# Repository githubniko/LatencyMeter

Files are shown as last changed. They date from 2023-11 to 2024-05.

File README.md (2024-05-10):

# Latency Meter FPV-systems & Camera

Устройство для измерения раздержки различных камер и FPV-систем. Оно построено на плате Ардуино Нано и 4х разрядном 7ми-сегментном индиаторе LED 5461AS-1.

* Версия 1.1 (для 2х-цветного светодиода): [https://github.com/githubniko/LatencyMeter/tree/v1.1](https://github.com/githubniko/LatencyMeter/tree/v1.1)
* Версия 2.0: отличие от 1.1 равномерым миганием без ожидания: [https://github.com/githubniko/LatencyMeter/tree/v2.0](https://github.com/githubniko/LatencyMeter/tree/v2.0)

**Кнопка:** Длинное нажатие на кнопку запускает процесс измерения сначала. Короткое - переключает показания индикатора между real-time, min, max, sma.

Видео по сборке: [https://www.youtube.com/watch?v=69uGeqPZ3CI](https://www.youtube.com/watch?v=69uGeqPZ3CI)

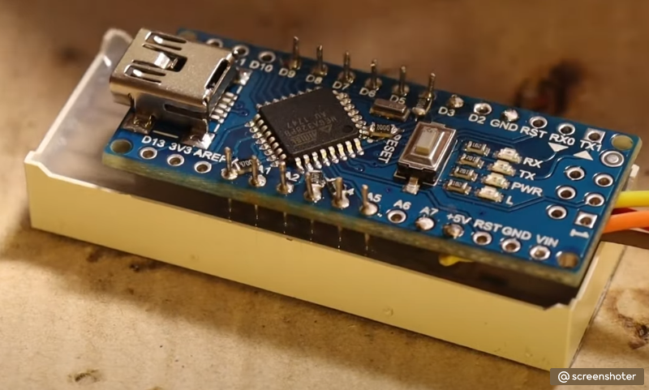
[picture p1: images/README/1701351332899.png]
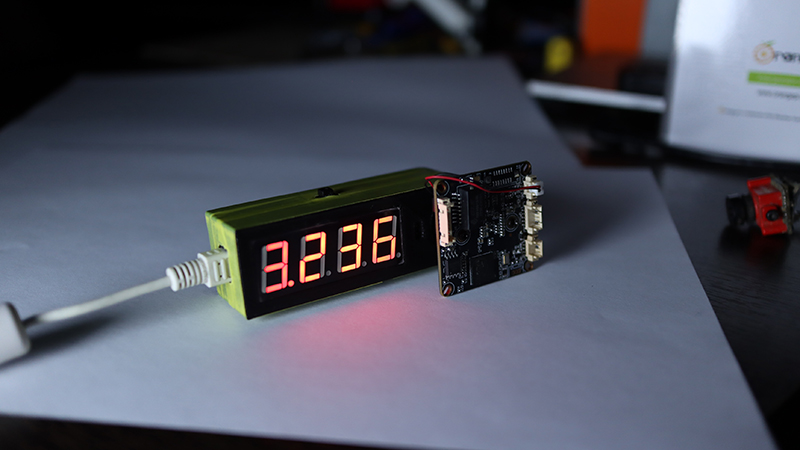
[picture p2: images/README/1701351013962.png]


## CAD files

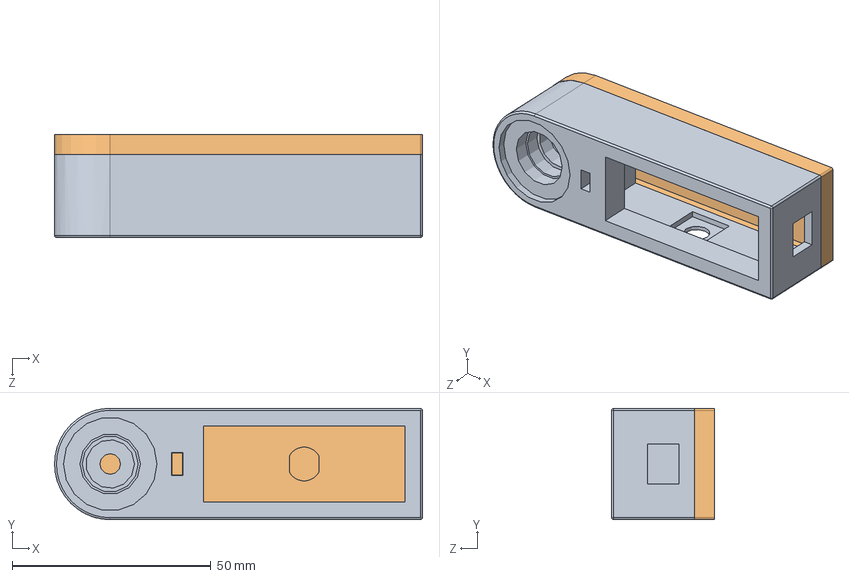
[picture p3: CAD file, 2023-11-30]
3d_model/Latency_IPCam.SLDASM
92.5 x 28.0 x 25.9 mm
Latency_IPCam
Крышка^Latency_IPCam

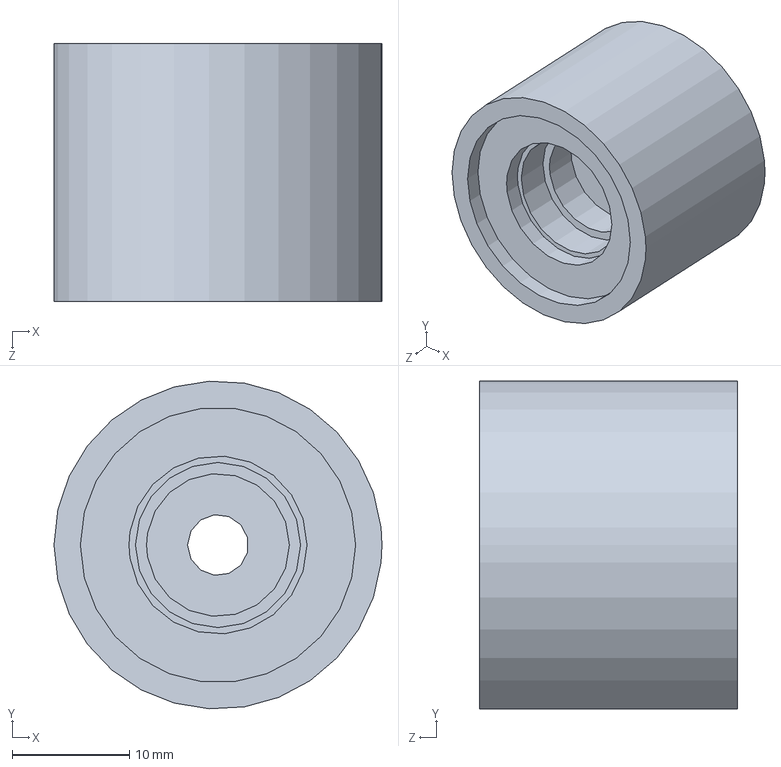
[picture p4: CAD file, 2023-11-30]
3d_model/Lens_housing.SLDPRT
28.0 x 28.0 x 22.0 mm

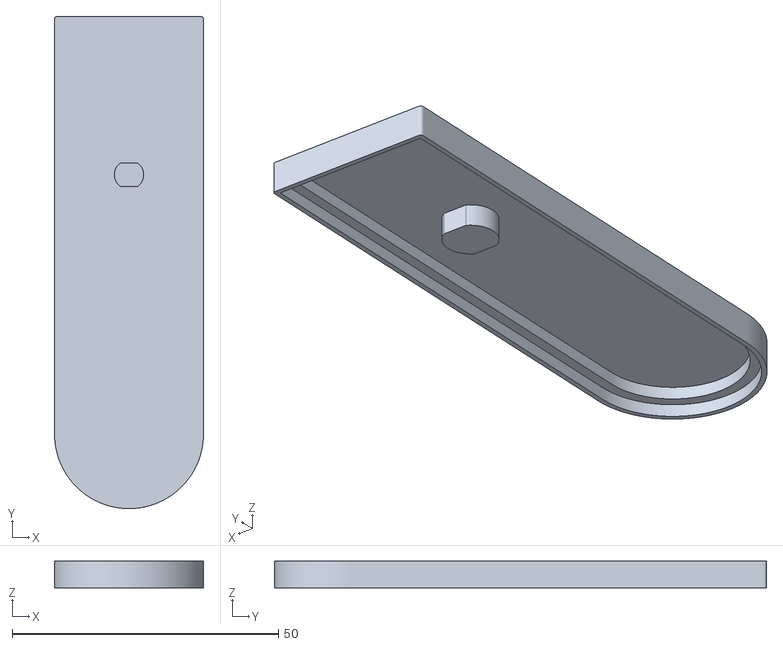
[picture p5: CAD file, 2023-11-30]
3d_model/STL/Latency_IPCam2.STL
28.0 x 92.5 x 5.00

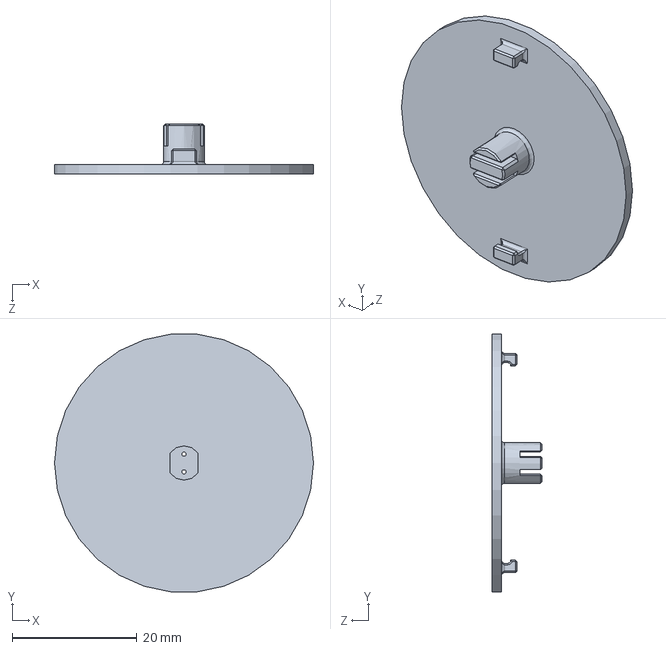
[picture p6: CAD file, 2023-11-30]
3d_model/Housing_for_VT83N1.SLDPRT
41.5 x 41.3 x 8.00 mm

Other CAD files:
3d_model/Latency_IPCam.SLDPRT
3d_model/STL/Housing_for_VT83N1.STL
3d_model/STL/Latency_IPCam.STL
3d_model/STL/Lens_housing.STL

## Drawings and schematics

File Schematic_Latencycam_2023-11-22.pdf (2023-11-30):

A | A

1

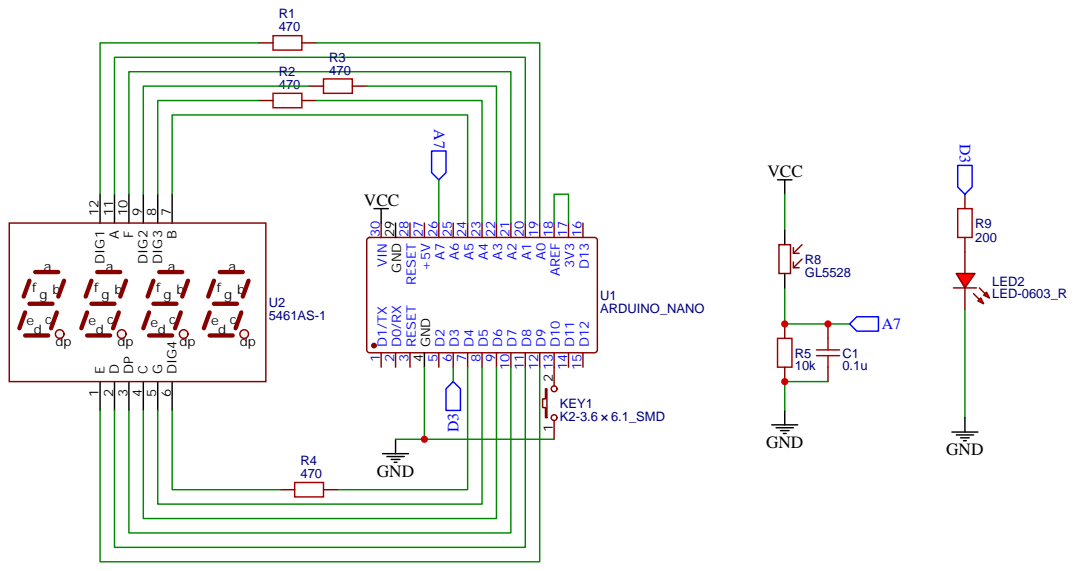
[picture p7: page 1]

D12 15 D13 16 3V3 17 AREF 18 A0 19 A1 20 A2 21 A3 22 A4 23 A5 24 A6 25 A7 26 +5V 27 RESET 28 GND 29 VIN 30

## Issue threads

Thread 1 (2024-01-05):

Неустойчивость длительности свечения светодиода

KimIV, 2024-01-05:
Я собрал Вашу схему на макетке для протестировать и залил последнюю версию скетча от 02.01.2024.

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

Схема сразу заработала в паре со скетчем, но напряг один момент. Я полагал так, что если светодиод направить на фоторезистор без посредников, то должна быть нулевая задержка. Но на индикаторе я увидел скачущие цифры от 0 до 3. Это было бОльшую часть времени наблюдения в течение нескольких десятков секунд. Но иногда (очень редко) проскакивали цифры 4, 5, 6 и 7. Я решил посмотреть осциллографом сигналы на светодиоде и фоторезисторе. Вот точки контроля по Вашей схеме.

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

И наблюдал интересную картину. Время свечения светодиода плавно увеличивалось. Потом резко уменьшалось и снова плавно увеличивалось. Но иногда резко увеличивалось и также резко уменьшалось. Вот ссылка на видео https://youtu.be/JZO6ssp1RjM

Тогда я решил откатиться к Вашей первоначальной версии latencymeter_old.hex Ситуация с нулевой задержкой на этой прошивке намного лучше. Цифры на индикаторе видны только 0 и 1. И время свечения светодиода уже не имеет плавных нарастаний, а есть только скачки. Вот скрины минимальной и максимальной длительностей свечения светодиода (жёлтый луч).

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

А также ссылка на видео https://youtu.be/XXs31W97c6k

PS. Я пока только обрисовал проблему. Изучаю Ваши исходники и пытаюсь понять, где собака порылась...

KimIV, 2024-01-05:
Ну и по ходу дела ещё один нюанс, на который я обратил внимание. У меня почему-то нет вот этой задержки между момент зажигания светодиода и моментом начала реакции фоторезистора. Вот скрин из Вашего видео по сборке. А мои скрины в предыдущем сообщении.

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

githubniko, 2024-01-05:
Эта задержка на последнем скриншоте не нужна. Почему она у меня была на видео не стал выяснять. Что касается плавного нарастания на осциллограммах, то оно у Вас ~0.8мс, у меня было на старой прошивке ~0.03мс. Новую прошивку не смотрел осциллографом. После праздников проверю обязательно.
Попробуйте закомментировать ресурсную функцию расчета медианы в latencymeter.h:90. Так же можно попробовать исключить конденсатор С1 на фоторезисторе. Еще важно, чтобы на фоторезистор не поступал лишний свет.

KimIV, 2024-01-06:
> Эта задержка на последнем скриншоте не нужна.

Это-то как раз понятно. Даже если бы она была, её необходимо было бы компенсировать программно. Просто я шёл по Вашим следам и удивлялся, почему мои "деревья растут вверх ногами" ))) Были даже сомнения сначала, может я где напортачил и что-то сделал не так. Какое-то время потратил на перепроверки. Ну и потом решил Ваше внимание обратить на это...

> Что касается плавного нарастания на осциллограммах, то оно у Вас ~0.8мс, у меня было на старой прошивке ~0.03мс.

Вы имеете в виду бинарник latencymeter_old.hex? Или была прошивка ещё первее? Просто два последних скрина в моём первом сообщении - это именно эта прошивка и там фронт импульса на фоторезисторе нарастает в диапазоне от 0,3 до 0,75мс. Я думаю, это скорострельность самого фоторезистора. Не смотря на то, что фронт параболический, можно всё-таки приближённо грубо взять за скорость нарастания фронта 0,2мс/В. И это даже компенсировать никак не надо, поскольку разрешение самого прибора 1мс. Меня больше волнует, почему идёт накопление задержки до 2 и даже изредка до 3мс.

> Попробуйте закомментировать ресурсную функцию расчета медианы в latencymeter.h:90.

Ооо... Вы как разработчик интуитивно чувствуете, где может быть засада! Отключение расчёта медианы стабилизировало длительность свечения светодиода. И она составила примерно 0,5мс.

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

> Так же можно попробовать исключить конденсатор С1 на фоторезисторе.

Это я пробовал. На последней прошивке его влияние уловить трудно, практически невозможно. Я не смог! А вот на бинарнике latencymeter_old.hex чётко видно, что конденсатор увеличивает время между вспышками светодиода. Ниже скрины с конденсатором и без.

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

> Еще важно, чтобы на фоторезистор не поступал лишний свет.

Да, я тоже это заметил. Лишний свет увеличивает "нулевую" задержку, т.к. реакция фоторезистора - это левая часть перевёрнутой параболы,

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

то "лишний" свет поднимает вверх по этой параболе рабочий участок и таким образом увеличивает время реакции фоторезистора. Я эту проблему решил, соединив фоторезистор со светодиодом бумажным тубусом.

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

> Почему-то у Вас напряжение на фотодиоде очень большое. Должно быть стартовое +0.5В. Установлено ли Uref = 3.3 ?

Да, установлено. Вывод REF наны соединён с выводом 3V3 и на данный момент там напряжение 3,236 В. Возможно, мне следует уменьшить сопротивление резистора R5. Это который 10к. Мой фоторезистор в темноте имеет сопротивление порядка 100к, а при ярком освещении - около 1к. Это обычный фоторезистор из комплекта Arduino Ultimate Uno R3 Starter Kit.

KimIV, 2024-01-06:
> Попробуйте закомментировать ресурсную функцию расчета медианы в latencymeter.h:90.

Я посидел над кодом, поразмышлял и мне стала понятная природа плавного нарастания времени свечения светодиода. Это происходит из-за увеличения списка данных, которые используются при расчёте медианы. Время работы функции median() прямопропорционально количеству данных, которое постепенно увеличивается. И что важно, это никак не влияет на "нулевую" задержку. То есть при плавном увеличении времени свечения светодиода мы всё равно можем наблюдать резкие скачки этого времени туда-сюда. А когда смотрим в монитор порта (туда пишет Serial.println(value); (latencymeter.h:119)), то видим цифры 0, 1, 2. Кстати, после того, как я соединил тубусом фоторезистор и светодиод перестала проскакивать цифра 3. И этот факт возвращает к мысли, что быстродействие фоторезистора может быть той самой собакой, которая порылась )))

KimIV, 2024-01-08:
После замены функции millis() на [micros()](https://github.com/githubniko/LatencyMeter/pull/3/commits/135b7523a1be15ed3dfb1190a304873c977ac3e8) я посмотрел осциллографом импульсы в тех же точках, которые указывал в первом сообщении. И вот, что увидел. Длительность свечения светодиода плавно растёт с момента старта измерений с 0,8 мс до 12 мс и далее стабилизируется. Изменение происходит только в первые 30 секунд. После этого длительность импульса постоянна и если точно составляет 11,88 мс.

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

[Ссылка на видео](https://youtu.be/riIVxjTF750), демонстрирующее процесс.

Меня лично вот это стартовое нарастание длительности свечения светодиода уже мало беспокоит. Главное, что удалось устранить непонятные скачки длительности свечения и нулевой задержки.

Что ещё имею сообщить? Для проверки я выводил в serial разницу между micros() и _timer, то есть до деления на 1000 для получения миллисекунд.

`                valueTime = (micros() - _timer) / 1000; // Считаем задержку`
`                Serial.print(micros() - _timer, DEC);`
`                Serial.print(' ');`
`                AddValue(valueTime);`

Так вот диапазон этих значений для нулевой задержки от 340 до 368 на довольно большой выборке (несколько тысяч). А типовое значение равно 344.

Closed 2024-01-09.

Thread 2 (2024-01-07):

Latency Meter. Неустойчивость LOW.

KimIV, 2024-01-07:
Я обнаружил ещё одну проблему. Но прежде, чем изложить её суть, предлагаю договориться о терминах. Предлагаю называть нулевой задержкой ситуацию, при которой светодиод направлен на фоторезистор либо в полной темноте, либо через тубус, который исключает попадание на фоторезистор постороннего света. Например, у меня это реализовано вот так.

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

Теперь суть проблемы. Я заметил, что при нулевой задержке скачет значение LOW. Я считаю, что LOW в данном случае всегда должно быть равно нулю. Вот ссылка на видео, демонстрирующее скачки LOW. То 0 (ноль), то 1 (единица).

https://youtu.be/nGoV20tnr8o

PS. Версия скетча последняя с закомментированным расчётом медианы
latencymeter.h:90`//                medianTime = round(median());`

githubniko, 2024-01-07:
Спасибо. Это баг. см latencymeter.h:84
Будет возникать когда minTime = 0.

githubniko, 2024-01-07:
Заднюю часть светодиода желательно закрасить черной краской.

Closed 2024-01-09.

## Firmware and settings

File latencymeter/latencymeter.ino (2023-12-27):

#define F_CPU 16000000UL // частота работы микроконтроллера

#define PIN_BUTTON 10

#include "Led_5461AS.h"
#include "Button.h"
#include "LatencyMeter.h"

Led_5461AS *led;
LatencyMeter *latencyMeter;
Button button1(PIN_BUTTON);

uint8_t flagTypeDataOut = 3; // 0 - задержка рела-тайм, 1 - минимальная, 2 - максимальная, 3 - медиана, 4 - кол-во измерений

class EventHandler
{
public:
  void OnUpdateData()
  {
    char buf[33];
    char str[10];

    switch (flagTypeDataOut)
    {
    case 1:
      dtostrf(latencyMeter->minTime, 3, 0, buf);
      strcpy(str, "L");
      break;
    case 2:
      dtostrf(latencyMeter->maxTime, 3, 0, buf);
      strcpy(str, "H");
      break;
    case 3:
      dtostrf(latencyMeter->medianTime, 3, 0, buf);
      strcpy(str, "^");
      break;
    case 4:
      itoa(latencyMeter->count, buf, 10);
      strcpy(str, "n");
      break;
    case 0:
    default:
      dtostrf(latencyMeter->valueTime, 4, 0, buf);
      strcpy(str, "");
      break;
    }
    strcat(str, buf);
    led->Set(str); // вывод на экран
  }
  void OnBtnClick()
  {
    flagTypeDataOut++;
    if (flagTypeDataOut > 4)
      flagTypeDataOut = 0;
    
    OnUpdateData();
  }
  void OnBtnReset()
  {
    latencyMeter->Start();
    // asm volatile("jmp 0x00"); // Перезагрузка
  }
};
EventHandler eventHandler;

void setup()
{
  Serial.begin(115200);

  led = new Led_5461AS();
  latencyMeter = new LatencyMeter();
  latencyMeter->onUpdate += METHOD_HANDLER(eventHandler, EventHandler::OnUpdateData);

  button1.onClick += METHOD_HANDLER(eventHandler, EventHandler::OnBtnClick);
  button1.onClickLong += METHOD_HANDLER(eventHandler, EventHandler::OnBtnReset);

  //latencyMeter->Start();
}

void loop()
{
  button1.Execute();
  latencyMeter->Execute();
}

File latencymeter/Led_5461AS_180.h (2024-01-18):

#pragma once

#define A PORTD5    // D5
#define B PORTB1    // D9
#define C PORTC2    // A2
#define D PORTC4    // A4
#define E PORTC5    // A5
#define F PORTD6    // D6
#define G PORTC1    // A1
#define DP PORTC3   // A3
#define DIG1 PORTD4 // D4
#define DIG2 PORTD7 // D7
#define DIG3 PORTB0 // D8
#define DIG4 PORTC0 // A0

#include <math.h>

class Led_5461AS
{
    static inline uint8_t count;
    static inline uint8_t offset; // Смещение. Нужно для точки или запятой
    static inline char *value;    // Хранит текущее число индикации

public:
    static inline uint8_t Length; // Размер строки

public:
    Led_5461AS()
    {
        value = "0";
        count = 1;
        offset = 0;
        Length = strlen(value);

        // Устанавливаю порты на выход
        DDRB = DDRB | B00011;
        DDRC = DDRC | B00111111;
        DDRD = DDRD | B11110000;

        // Таймер обновления индикации
        cli(); // отключить глобальные прерывания
        TCCR1A = 0;
        TCCR1B = 0;
        TCCR1B |= (1 << CS11);   // делитель 8
        TCCR1B |= (1 << WGM12);  // сброс по совпадению
        OCR1A = 2500;            // 10ms, 100Гц*4 = 480Гц, 16 000 000 / 8 * 400Гц * 2 = 2500
        TIMSK1 |= (1 << OCIE1A); // прерывание по переполнению

        sei(); // включить глобальные прерывания
    }

    /// @brief Устанавливает значение индикатора
    void Set(float number)
    {
        if (number > 9999)
            number = 9999;

        uint8_t pos = FindDecimalPoint(number);
        char buf[33];
        dtostrf(number, 4, 4 - pos, buf);
        Set(buf);
    }

    /// @brief Устанавливает значение индикатора
    void Set(int number)
    {
        if (number > 9999)
            number = 9999;

        char buf[33];
        itoa(number, buf, 10);
        Set(buf);
    }

    /// @brief Устанавливает значение индикатора
    void Set(const char *str)
    {
        strcpy(value, str);
        Length = strlen(value);
    }

    /// @brief Метод обновления индикации
    static void Update()
    {
        bool dp = false;
        char symbol;
        TurnOff();

        int i = Length - 4 + count - 1;
        symbol = i < 0 ? ' ' : value[i - offset];

        if (symbol == '.' || symbol == ',')
        {
            dp = true;
            offset++;
            symbol = i - offset < 0 ? ' ' : value[i - offset];
        }

        Digit(symbol, dp);
        TurnOnNumber(count);

        count--;

        if (count == 0)
        {
            count = 4;
            offset = 0;
        }
    }

private:
    /// @brief Устанавливает число на индикаторе
    static void Digit(char val, bool dp = false)
    {
        DigitOff();

        switch (val)
        {
        case '1':
            PORTB = PORTB | (1 << B);
            PORTC = PORTC | (1 << C);
            break;
        case '2':
            PORTB = PORTB | (1 << B);
            PORTC = PORTC | (1 << D) | (1 << E) | (1 << G);
            PORTD = PORTD | (1 << A);
            break;
        case '3':
            PORTB = PORTB | (1 << B);
            PORTC = PORTC | (1 << C) | (1 << D) | (1 << G);
            PORTD = PORTD | (1 << A);
            break;
        case '4':
            PORTB = PORTB | (1 << B);
            PORTC = PORTC | (1 << C) | (1 << G);
            PORTD = PORTD | (1 << F);
            break;
        case '5':
            PORTC = PORTC | (1 << C) | (1 << D) | (1 << G);
            PORTD = PORTD | (1 << A) | (1 << F);
            break;
        case '6':
            PORTC = PORTC | (1 << C) | (1 << D) | (1 << E) | (1 << G);
            PORTD = PORTD | (1 << A) | (1 << F);
            break;
        case '7':
            PORTB = PORTB | (1 << B);
            PORTC = PORTC | (1 << C);
            PORTD = PORTD | (1 << A);
            break;
        case '8':
            PORTB = PORTB | (1 << B);
            PORTC = PORTC | (1 << C) | (1 << D) | (1 << E) | (1 << G);
            PORTD = PORTD | (1 << A) | (1 << F);
            break;
        case '9':
            PORTB = PORTB | (1 << B);
            PORTC = PORTC | (1 << C) | (1 << D) | (1 << G);
            PORTD = PORTD | (1 << A) | (1 << F);
            break;
        case '0':
            PORTB = PORTB | (1 << B);
            PORTD = PORTD | (1 << A) | (1 << F);
            PORTC = PORTC | (1 << C) | (1 << D) | (1 << E);
            break;
        case 'H':
            PORTB = PORTB | (1 << B);
            PORTC = PORTC | (1 << C) | (1 << E) | (1 << G);
            PORTD = PORTD | (1 << F);
            break;
        case 'h':
            PORTC = PORTC | (1 << C) | (1 << E) | (1 << G);
            PORTD = PORTD | (1 << F);
            break;
        case 'L':
            PORTC = PORTC | (1 << D) | (1 << E);
            PORTD = PORTD | (1 << F);
            break;
        case 'l':
            PORTC = PORTC | (1 << E);
            PORTD = PORTD | (1 << F);
            break;
        case ' ':
            PORTB = PORTB & ~(1 << B);
            PORTC = PORTC & ~(1 << C) & ~(1 << D) & ~(1 << E) & ~(1 << G) & ~(1 << DP);
            PORTD = PORTD & ~(1 << A) & ~(1 << F);
            break;
        case '-':
            PORTC = PORTC | (1 << G);
            break;
        case 'U':
        case 'u':
            PORTB = PORTB | (1 << B);
            PORTC = PORTC | (1 << C) | (1 << D) | (1 << E);
            PORTD = PORTD | (1 << F);
            break;
        case '^':
            PORTD = PORTD | (1 << A) | (1 << F);
            break;
        case 'n':
            PORTC = PORTC | (1 << C) | (1 << E) | (1 << G);
            break;
        default:
            break;
        }

        if (dp)
            PORTC = PORTC | (1 << DP);
    }
    /// @brief Сбрасывает значения цифры
    static void DigitOff()
    {
        PORTB = PORTB & ~(1 << B);
        PORTC = PORTC & ~(1 << C) & ~(1 << D) & ~(1 << E) & ~(1 << G) & ~(1 << DP);
        PORTD = PORTD & ~(1 << A) & ~(1 << F);
    }
    /// @brief Выключает все разряды
    static void TurnOff()
    {
        PORTB = PORTB | (1 << DIG3);
        PORTC = PORTC | (1 << DIG4);
        PORTD = PORTD | (1 << DIG1) | (1 << DIG2);
    }
    /// @brief Включает разряд c порядковым номером.Слева направо
    static void TurnOnNumber(uint8_t num)
    {
        switch (num)
        {
        case 1:
            PORTD = PORTD & ~(1 << DIG1);
            break;
        case 2:
            PORTD = PORTD & ~(1 << DIG2);
            break;
        case 3:
            PORTB = PORTB & ~(1 << DIG3);
            break;
        case 4:
            PORTC = PORTC & ~(1 << DIG4);
            break;

        default:

            break;
        }
    }

    /// @brief Возвращает позицию запятой в числе
    static uint8_t FindDecimalPoint(float number)
    {
        for (uint8_t i = 0; number != 0; ++i)
        {
            if ((uint8_t)number == 0)
            {
                if (i == 0)
                    i++;
                return i;
            }
            number /= 10;
        }

        return 1;
    }
};
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

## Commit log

2023-11-30 Динамическая индикация
2023-11-30 Добавил измерения
2023-11-30 Испр. название метода DigitOff()
2023-12-13 Доб. отображение строки на индикаторе
2023-12-14 Перенос кода в класс LatencyMeter
2023-12-14 Форматирование кода
2023-12-14 Обновленн класс Button
2023-12-14 Переключание режимов real-time, min, max, sma
2023-12-14 Изм. описания
2023-12-14 Доб. вывод кол-ва измерений
2023-12-27 добавлена медиана, по-умолчанию
2023-12-28 Оптимизация памяти, медиана без сортировки
2024-01-02 Испр. алгоритм нахождения медианы
2024-01-02 Оптимизация верх/нижн предела нахождения медианы
2024-01-02 Доб. комментарии
2024-01-07 Update latencymeter.h
    Я проверил. Если убрать сравнение minTime с нулём, то LOW перестаёт скакать.
2024-01-07 Update latencymeter.h
    Мне удалось убрать 2 в нулевой задержке, заменив millis() на micros() / 1000. Теперь в нулевой задержке фигурируют только 0 и 1. Думаю, с этим уже можно смириться...
2024-01-07 Исправление нулевой задержки
    Немного изменил расчёт valueTime, а также в переменной _timer теперь хранится micros(). Нулевая задержка теперь действительно нулевая!
    [latencymeter.h]
2024-01-09 Исправление постоянного нуля в LOW
    Переменную minTime инициировал максимальным для её типа значением 32767. И сделал это после вызова метода onUpdate(). Если это сделать до вызова метода onUpdate() и короткими нажатиями кнопкой настроить отображение LOW, то на короткое время мелькает значение 2767 (тройка не входит по разрядности). Поэтому я принял решение до вызова метода onUpdate() оставить minTime = 0, а пос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
    [latencymeter.h]
2024-01-09 Исправил опечатки в комментах
    [latencymeter.h]
2024-01-16 Update Led_5461AS.h
    Давненько уже обнаружил этот небольшой косячок, но поначалу воспринимал, как некую особенность, пока случайно не исправил. Косячок состоит в том, что при нажатии на кнопку притухают сегменты E индикатора. А если вывод D10, PORTB2 инициировать нулём, то притухания больше нет.
    [Led_5461AS.h]
2024-01-18 Расположение Led на 180 градусов.
2024-05-03 Испр. многократного срабатывания при коротком нажатии.
2024-05-05 Ложное срабатывание кнопки
